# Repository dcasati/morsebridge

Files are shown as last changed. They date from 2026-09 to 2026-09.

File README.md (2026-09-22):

# MorseBridge

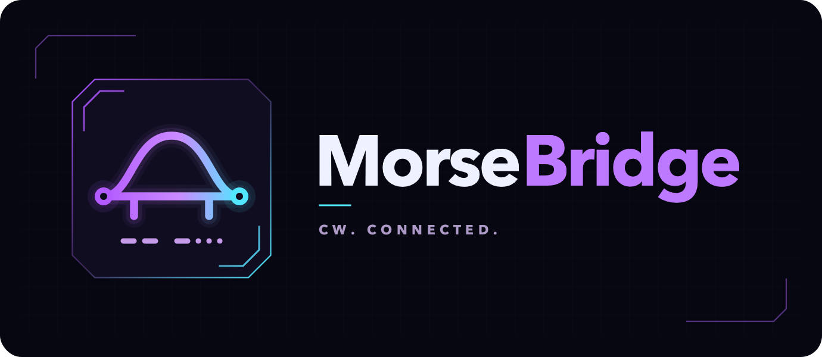
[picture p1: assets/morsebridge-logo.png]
MorseBridge - CW. CONNECTED.


**Use your Morse paddle with your favorite CW app, over USB or Bluetooth.**
MorseBridge is a small adapter built around the **Waveshare ESP32-S3-Zero**.
It turns paddle presses into keyboard input; the app handles Morse timing and
sidetone. No display, menus or standalone computer are needed when using a phone.

<p align="center">
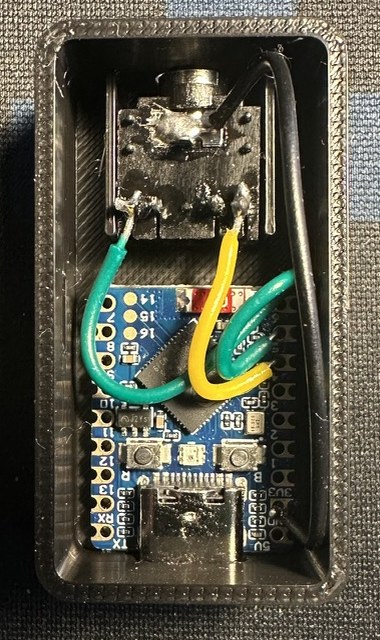
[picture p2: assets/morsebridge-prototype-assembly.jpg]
MorseBridge prototype with the lid removed, showing the jack, wiring and ESP32 board
  
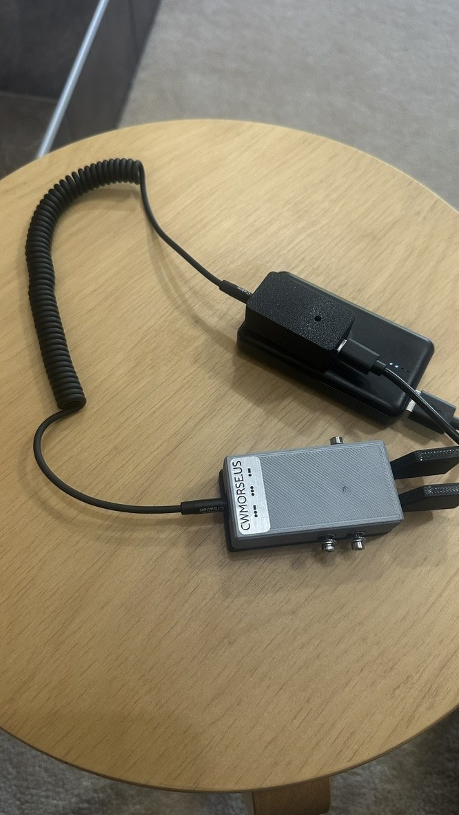
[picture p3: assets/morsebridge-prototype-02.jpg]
Second user-supplied MorseBridge prototype photo
  
</p>

## How it connects

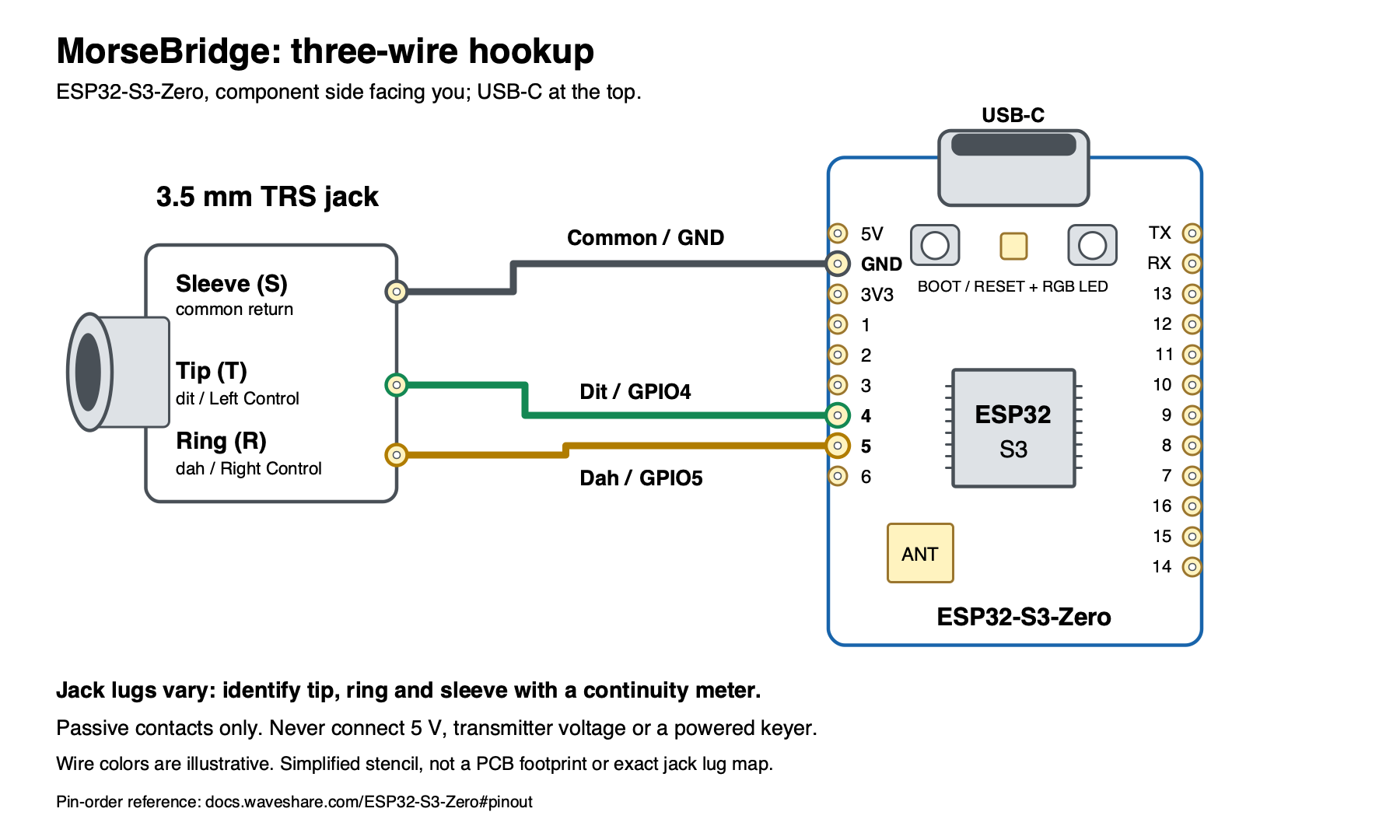
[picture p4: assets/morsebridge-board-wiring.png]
ESP32-S3-Zero component-side wiring: jack tip to GPIO4 for dit, ring to GPIO5 for dah, and sleeve to GND, with USB-C at the top.


**USB-C is at the top; the board's component side faces you.** Jack terminals
are symbolic: identify the actual tip, ring and sleeve lugs with a continuity meter.

**USB takes priority when a host configures it.** With a charger or power bank,
use Bluetooth instead. Only one connection sends paddle input at a time.

## Get started

You need an **ESP32-S3-Zero (4 MB flash / 2 MB PSRAM)**, a passive iambic
paddle, a 3.5 mm TRS jack and a USB-C data cable.

1. **Wire the jack:** tip to **GPIO4** (dit), ring to **GPIO5** (dah), sleeve to
   **GND**. Verify the jack's lug mapping before soldering.
2. **Download the [latest firmware release](https://github.com/dcasati/morsebridge/releases/latest)**
   and follow the [flashing instructions](docs/flashing.md). No compiling required.
3. **Connect:** use a USB-C data cable to your phone/computer, or power from a
   charger/power bank and pair with **MorseBridge** over Bluetooth.
4. **Configure the app:** enable keyboard/paddle input, set **dit = Left Control**
   and **dah = Right Control**, then open its sending screen.
5. **Release both paddles to arm**, then start sending. Repeat after changing
   connections. [Morse-it setup details](docs/guide.md#iphone-and-morse-it).

**Passive contacts only:** never connect transmitter/keying voltage, 5 V or a
powered keyer output to the GPIOs. Straight-key mode is not supported yet.

## Known-working apps

User-confirmed; individual USB/Bluetooth and device/browser combinations are
not yet documented.

- [Morse Code Complete: Learn CW](https://apps.apple.com/ca/app/morse-code-complete-learn-cw/id6759272226)
- [Morse-It](https://apps.apple.com/ca/app/morse-it/id284942940)
- [VBand](https://hamradio.solutions/vband/)

## Status light

| Color | Meaning |
| --- | --- |
| Cyan | USB ready |
| Green | Bluetooth ready |
| Blue | Waiting for a connection |
| Amber | Waiting for readiness, USB resume or paddle release |
| Red | Connection/report error; reset and check [diagnostics](docs/guide.md#diagnostics-and-behavior) |

A Mac/PC data connection selects USB even when you only open a serial monitor.
Use a charger or power bank when you want Bluetooth input on another device.

## Print a case

**45 x 24 x 16 mm enclosure**, with a snap-fit lid and release slots.

Download and print the linked base and lid as a matching pair. The prototype
was printed in **PLA+**; **PETG is also an option**. Check fit and clip strength
before installing the electronics.

[Base STL](enclosure/v6/morsebridge_base_45x24x16_v6.stl) |
[Lid STL](enclosure/v6/morsebridge_lid_45x24x16_v6.stl) |
[Printing and fit notes](enclosure/FIT-CHECK.txt)

## Guides

[Build, flash and BOOT recovery](docs/guide.md#build) |
[Troubleshooting](docs/guide.md#diagnostics-and-behavior) |
[BLE-only rollback](docs/guide.md#ble-only-rollback) |
[Editable wiring diagram](assets/morsebridge-board-wiring.excalidraw)

## License

[MIT](LICENSE). Adapted from [Morse Tutor](https://github.com/dcasati/morse-tutor),
retaining the original **Copyright (c) 2019 Bruce E. Hall** notice.
[Provenance details](docs/guide.md#provenance-and-license).

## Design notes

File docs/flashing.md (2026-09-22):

# Flash a firmware release

For the **Waveshare ESP32-S3-Zero with 4 MB flash and 2 MB PSRAM** only.
This is not firmware for the original ESP32-WROOM, a XIAO board, or the
ESP32-S3-Zero-N8R8.

## 1. Download

From the [latest release](https://github.com/dcasati/morsebridge/releases/latest),
download the firmware ZIP and `SHA256SUMS.txt`. Use the firmware ZIP, **not**
GitHub's automatically generated "Source code" archives.

Verify the ZIP before extracting it. On macOS:

```sh
shasum -a 256 -c SHA256SUMS.txt
```

On Linux, use `sha256sum -c SHA256SUMS.txt`. On Windows, use
`Get-FileHash .\morsebridge-v0.1.0-esp32s3-zero.zip -Algorithm SHA256` in
PowerShell and compare the result with `SHA256SUMS.txt`.

Extract the ZIP. It contains:

| File | Flash address |
| --- | --- |
| `bootloader.bin` | `0x0` |
| `partitions.bin` | `0x8000` |
| `boot_app0.bin` | `0xe000` |
| `firmware.bin` | `0x10000` |

`FLASHING.md`, `build-details.json`, `LICENSE` and a separate `SHA256SUMS.txt`
for the extracted files are included. **Do not flash `firmware.bin` at `0x0`.**

## 2. Install the flashing tool

Install Python 3 if needed, then create a virtual environment.

macOS / Linux:

```sh
python3 -m venv .venv
source .venv/bin/activate
```

Windows PowerShell:

```powershell
py -m venv .venv
.\.venv\Scripts\Activate.ps1
```

In the activated environment:

```sh
python -m pip install esptool==5.2.0
```

Arduino IDE and the ESP32 board package are not needed for this method.

## 3. Enter download mode and flash

Use a **USB data cable** and close serial monitors. Hold **BOOT**, tap and
release **RESET**, then release BOOT. Alternatively, hold BOOT while plugging
the board into USB.

Find the board's serial port: typically `/dev/cu.usbmodem...` on macOS,
`/dev/ttyACM0` on Linux, or `COM3` on Windows. The name can change in BOOT mode.
Unplug/replug to distinguish it from other serial devices.

In a terminal with the virtual environment active, change into the extracted
firmware folder. Replace `PORT` below with the board's actual port, then run
this command as **one line**:

```sh
python -m esptool --chip esp32s3 --port PORT --baud 115200 write-flash 0x0 bootloader.bin 0x8000 partitions.bin 0xe000 boot_app0.bin 0x10000 firmware.bin
```

Wait for verification to finish, then tap **RESET** if the board remains in
download mode.

This command writes four separate regions; it does **not** run `erase-flash`
or overwrite the NVS region at `0x9000`-`0xdfff`. Existing MorseBridge Bluetooth
bonds are preserved when updating from its current partition layout. Back up
any important data before replacing unrelated firmware; its partition layout
may differ. No merged whole-flash image is included.

## 4. Start using MorseBridge

Release both paddles after connection. **Cyan** means USB ready; **green**
means Bluetooth ready. Configure the app for **dit = Left Control** and
**dah = Right Control**.

A Mac/PC USB data connection selects wired input. To use Bluetooth with your
phone, power the board from a charger or power bank instead.

For troubleshooting, source builds or BLE-only rollback, see the
[setup and firmware guide](https://github.com/dcasati/morsebridge/blob/main/docs/guide.md).

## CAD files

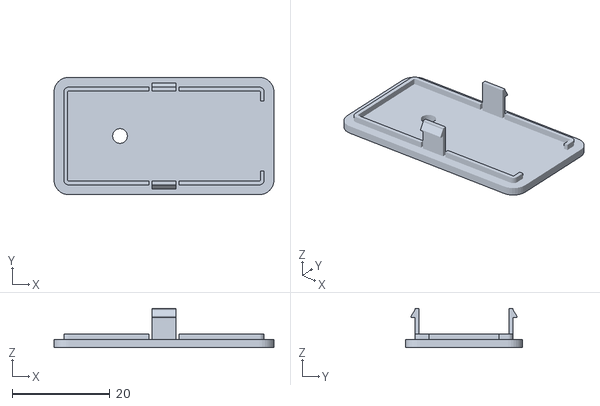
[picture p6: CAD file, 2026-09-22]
enclosure/v6/morsebridge_lid_45x24x16_v6.stl
45.0 x 24.0 x 8.00

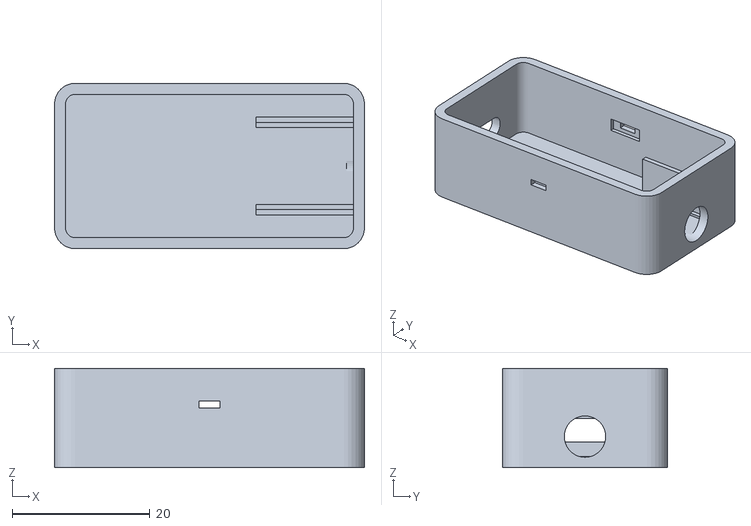
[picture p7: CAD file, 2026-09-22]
enclosure/v6/morsebridge_base_45x24x16_v6.stl
45.0 x 24.0 x 14.4

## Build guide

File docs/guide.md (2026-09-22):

# MorseBridge setup and firmware reference

[Back to the overview](../README.md)

Detailed instructions for building, configuring and troubleshooting MorseBridge.
Run all shell commands from the **repository root**, not from `docs/`.

- [Hardware and wiring](#hardware-and-wiring)
- [Build](#build)
- [Upload and BOOT recovery](#upload-and-boot-recovery)
- [BLE-only rollback](#ble-only-rollback)
- [iPhone and Morse-it](#iphone-and-morse-it)
- [Diagnostics and behavior](#diagnostics-and-behavior)
- [Enclosure prototype](#enclosure-prototype)

## Validation record

The previous BLE-only build
(`c055d0d`) was flashed and used successfully with paddles in Morse-it.
The dual-transport build passes host tests and the pinned ESP32-S3 build.
Firmware `70bdd09` was flashed on the S3 on 2026-09-22 without erasing NVS.
macOS recognizes **MorseBridge as a USB HID keyboard** with diagnostic CDC.
Live diagnostics show USB configured, awake and armed, a queued neutral report,
and the existing bonded BLE connection retained with BLE paddle reports disabled.
Application compatibility is [user-confirmed in the overview](../README.md#known-working-apps). Exact transport/platform
combinations and physical handoffs remain to be recorded; enumeration alone
does not establish application compatibility.

## Hardware and wiring

Target: [Waveshare ESP32-S3-Zero](https://www.waveshare.com/wiki/ESP32-S3-Zero),
ESP32-S3FH4R2, **4 MB flash, 2 MB QSPI PSRAM**, native USB-C.

| Passive 3.5 mm TRS jack | Board connection | Function |
| --- | --- | --- |
| Tip | GPIO4 | Dit / Left Control |
| Ring | GPIO5 | Dah / Right Control |
| Sleeve | GND | Common return |

Both contacts are configured as `INPUT_PULLUP`: a contact is pressed when it
closes to GND. Verify the actual paddle plug and jack lug mapping with a
continuity meter before connecting; some paddles reverse tip/ring. Swap those
two leads if needed. The numbers above are **GPIO numbers**, not physical pin
positions.

GPIO4 and GPIO5 are exposed, non-strapping pins, separate from native USB
GPIO19/20, flash/PSRAM and the onboard GPIO21 WS2812. Leave GPIO19/20 alone.
For noisy or longer wiring, optional external **10 kOhm pullups from each input
to 3.3 V** can supplement the internal pullups. Keep wiring short.
**Never connect 5 V, transmitter/keying voltage, or a powered keyer output to
these GPIOs.** This input is for isolated passive contacts only, not a
transmitter keying interface.

Power the board through USB-C from a computer, USB supply or power bank. Boot
does not wait for Serial or a USB host. Some power banks shut off with a
low-current load; use an always-on/low-current mode or an appropriate supply.
No battery measurement or charging circuit is implemented. The HID battery
service reports a fixed 100% for this USB-powered device.

## Build

For a prebuilt binary, use the [latest firmware release](https://github.com/dcasati/morsebridge/releases/latest)
and [release flashing instructions](flashing.md). The steps below are for
building from source.

Use **Arduino ESP32 core 3.3.8**, which includes the BLE library. Do not install
a third-party `ESP32 BLE Keyboard` or `NimBLE-Arduino` library for this sketch.
The build script checks the installed core version and does not install or
upgrade dependencies automatically.

```sh
arduino-cli core update-index \
  --additional-urls https://espressif.github.io/arduino-esp32/package_esp32_index.json
arduino-cli core install esp32:esp32@3.3.8 \
  --additional-urls https://espressif.github.io/arduino-esp32/package_esp32_index.json
bash scripts/test.sh
bash scripts/build.sh
```

The host tests require a C++17 compiler (`c++`, or set `CXX`). Set `ARDUINO_CLI`
if the CLI is not on PATH. Standard `ARDUINO_DIRECTORIES_DATA` and
`ARDUINO_DIRECTORIES_USER` environment variables can isolate the Arduino
installation from other projects.

Exact tested FQBN (also used by `scripts/build.sh`):

```sh
FQBN='esp32:esp32:esp32s3:USBMode=default,CDCOnBoot=default,MSCOnBoot=default,DFUOnBoot=default,UploadMode=default,CPUFreq=240,FlashMode=qio,FlashSize=4M,PartitionScheme=huge_app,PSRAM=enabled,DebugLevel=none,EraseFlash=none'
arduino-cli compile --fqbn "$FQBN" --warnings all \
  --build-path "$PWD/build/esp32s3" MorseBridge
```

Equivalent Arduino IDE selections:

| Setting | Value |
| --- | --- |
| Board | ESP32S3 Dev Module |
| ESP32 package version | 3.3.8 |
| USB Mode | USB-OTG (TinyUSB) |
| USB CDC On Boot | Disabled (firmware starts diagnostic CDC manually) |
| USB Firmware MSC / DFU On Boot | Disabled |
| Upload Mode | UART0 / Hardware CDC |
| CPU Frequency | 240 MHz |
| Flash Mode / Size | QIO 80 MHz / 4 MB |
| Partition Scheme | Huge APP (3 MB No OTA / 1 MB SPIFFS) |
| PSRAM | QSPI PSRAM |
| Core Debug Level | None |
| Erase All Flash Before Sketch Upload | Disabled (normally) |

The large app partition leaves ample room; the filesystem partition is unused
and no OTA updater is implemented. Build output is ignored by Git under
`build/esp32s3/`, including `MorseBridge.ino.bin`, its ELF, bootloader, partition
table and merged image. Use the CLI upload command below so all images go to
their correct offsets, rather than flashing the app binary at address zero.
HID and diagnostic CDC are registered before `USB.begin()`: do not enable CDC
on boot or change to Hardware CDC/JTAG. The sketch rejects those settings.
The prototype retains Arduino's default Espressif USB VID/PID; these are not a
commercial VID/PID assignment for MorseBridge.

**S3 backend note:** core 3.3.8 builds ESP32-S3 with **NimBLE**, whereas the
original ESP32 transport used Bluedroid. This project uses the core's unified
`BLE*` APIs with native NimBLE connection/security/subscription callbacks,
synchronous advertising-start results and automatically managed CCCDs. It
does not fake a Bluedroid compile flag or use a manually added `BLE2902`.
The version is pinned because BLE APIs and backend defaults differ across
core versions.

## Upload and BOOT recovery

Use a known **USB data cable**. Once the board is visible, find its actual port:

```sh
arduino-cli board list
```

With `FQBN` set exactly as above, replace the example port with the detected one:

```sh
PORT='/dev/cu.usbmodem...'
arduino-cli upload --fqbn "$FQBN" --port "$PORT" \
  --input-dir "$PWD/build/esp32s3" MorseBridge
```

If the board is not detected or the previous sketch prevents USB enumeration,
hold **BOOT**, tap and release **RESET**, then release BOOT. Alternatively hold
BOOT while plugging in USB-C. Select the newly enumerated port and upload.
After upload, tap RESET if it remains in the ROM download loader. The serial
port name can change between ROM download mode and the running firmware.
If no USB device appears even in BOOT mode, check the cable, port and board
power first; software cannot flash a device that the host does not enumerate.

Normal uploads preserve Bluetooth bonds in NVS. For persistent stale-bond
problems, **forget the device on the iPhone and deliberately erase board flash
before reuploading**: in Arduino IDE enable *Erase All Flash Before Sketch
Upload* for one upload, then restore Disabled. This removes **all** board data,
including bonds, not just the application. No erase is performed by the build
script, and there is no bond-reset button gesture or serial command.

### BLE-only rollback

The known BLE-only version is commit `c055d0d675da2caa005ef69cd9abcd4ecbf71870`.
Build it separately without switching branches or disturbing current edits:

```sh
mkdir -p build/ble-rollback
git archive c055d0d675da2caa005ef69cd9abcd4ecbf71870 MorseBridge scripts/build.sh \
  | tar -x -C build/ble-rollback
(cd build/ble-rollback && bash scripts/build.sh)
```

Enter BOOT mode as described above, select its port and upload the rollback
images using the **old** USB configuration:

```sh
BLE_FQBN='esp32:esp32:esp32s3:USBMode=hwcdc,CDCOnBoot=cdc,MSCOnBoot=default,DFUOnBoot=default,UploadMode=default,CPUFreq=240,FlashMode=qio,FlashSize=4M,PartitionScheme=huge_app,PSRAM=enabled,DebugLevel=none,EraseFlash=none'
arduino-cli upload --fqbn "$BLE_FQBN" --port "$PORT" \
  --input-dir "$PWD/build/ble-rollback/build/esp32s3" build/ble-rollback/MorseBridge
```

## iPhone and Morse-it

1. **Wired:** connect the board directly to the unlocked iPhone 15 Pro Max with
   a USB-C **data** cable; Bluetooth pairing is not required. Expect cyan after
   releasing the paddles. Follow any iOS accessory-unlock prompt.
   **Wireless:** power from a charger/power bank, then pair with **MorseBridge**
   in iPhone **Settings > Bluetooth**. Expect green after release. Pairing uses
   bonded, encrypted JustWorks without MITM protection; pair in a trusted place.
2. In Morse-it, open **Settings > Hardware Interface > Iambic/Memory** and enable
   **Keyboard Enabled**. Set **Dot = Left Control**, **Dash = Right Control**.
3. Set **Key Type = Iambic A** or **Iambic B** to match your preference, and choose
   speed/sidetone settings in Morse-it.
4. Open **Tap** or **Start Sending Trainer**. In a keyboard event viewer, tap
   its text area to give it focus before trying the paddles.
5. Release **both** paddles after connection, route changes, resume or
   subscription changes to arm, then send normally.

### Automatic transport selection

USB is selected only when its host configures the device, not from cable power,
CDC DTR or an open serial monitor. Both transports may remain connected, but
paddle presses go to only one. During a BLE-to-USB handoff, BLE gets a neutral
report first; if it cannot accept the release, the firmware requests a BLE
disconnect and waits for that callback before enabling USB reports. Each newly
selected route sends neutral and waits for both contacts to be released.

**A Mac/PC data connection selects USB too**, even if you only wanted a serial
monitor. To use BLE with the iPhone, power the board from a charger/power bank
instead. A suspended USB host retains priority (amber) until resume or USB
unmount; the firmware does not send duplicate keys through BLE during sleep.
If the board loses power when unplugged, it restarts when powered again.
With independent power, USB unmount permits BLE fallback; without VBUS sensing,
loss of data wires alone may look like host suspension rather than unmount.

Left Control is modifier `0x01`, Right Control is `0x10`, and a squeeze is
`0x11`. Each report has exactly eight bytes: modifier, zero reserved byte, six
zero key usages. Releases send modifier `0x00`; holds remain held without
artificial repeats or tap conversion. These are modifier events, **not
printable text**, so an ordinary text field may show nothing.

If Bluetooth says connected but Morse-it does nothing, check keyboard mapping,
the active sending screen/focus, and that both paddles were released. Disconnect
other hosts that may reconnect to the board. If iOS has cached an earlier
keyboard profile, forget the old device and pair again. The distinct name
avoids confusing it with *Morse Tutor*, but changing the name alone does not
clear a cached identity/bond on the same physical board.

**Name migration:** iOS may keep displaying the former name, *Morse Paddle*,
for an existing bond after the firmware rename. Reconnect first; if the label
stays cached, forget that device on the iPhone and pair with **MorseBridge**.
The rename does not erase bonds or change the HID report format or GPIO mapping.

## Diagnostics and behavior

USB diagnostic CDC is 115200 baud, with **no boot wait or host-delivery wait**.
Opening a serial monitor can reset some boards/USB configurations and interrupt
BLE; reconnect and release both paddles afterward. Logging is best effort:
without a reading host, messages may be dropped rather than delay keying.
All firmware output uses one non-waiting writer guard and reserves a complete
line in a fixed 192-byte buffer, draining it in FIFO-sized chunks without
interleaving other lines. The pinned core's CDC TX FIFO is only 64 bytes.
Queuing directly to TinyUSB avoids both the old
HWCDC full-buffer stall and core 3.3.8's `USBCDC::write` behavior that drops all
writes with a zero timeout. No code waits for the host to consume diagnostics.
BLE callbacks never wait for another log writer. Dropped lifecycle/error
messages are counted and reported as `LOG: dropped ...` once space returns;
current GPIO/USB/BLE snapshots resume automatically.
There are boot messages, USB/BLE error messages and status transitions.
Paddle diagnostics are currently enabled (`MORSEBRIDGE_DEBUG=1` in
`MorseBridge/PaddleDebug.h`). Set that default to `0`, or compile with
`-DMORSEBRIDGE_DEBUG=0`, to disable the additional snapshots.
The former `MORSE_PADDLE_DEBUG` compile flag remains a compatibility alias.

### Checking the jack and paddle over USB

Open the board's serial port at **115200 baud**. No iPhone connection is needed
to see the input levels, even if BLE startup fails. Press/release each paddle,
then squeeze both. Expect:

| Contact state | GPIO4 | GPIO5 |
| --- | --- | --- |
| Both released | HIGH | HIGH |
| Dit held | LOW | HIGH |
| Dah held | HIGH | LOW |
| Both held | LOW | LOW |

Example snapshot:

```text
DBG GPIO4=LOW GPIO5=HIGH edges=1/0 C=1 A=1 S=1 U=0 R=0 Q=1 M=00 T=USB UC=1 US=0 UR=1 UQ=2 UM=01
```

`edges` counts **raw transitions** on GPIO4/GPIO5 since boot, including contact
bounce; a short tap can increase the counters even if the sampled display has
already returned to HIGH. Changes are summarized at most ten times per second,
with a heartbeat every two seconds. The logger never waits for USB buffer
space, and retains transition totals while there is no reading host.

The BLE flags are `C` connected, `A` encrypted and bonded, `S` HID notifications
subscribed, `U` host suspended, and `R` ready/armed. `Q` counts reports accepted
by the local BLE stack since boot, **not confirmed delivery to Morse-it**.
`M` is the last accepted report's modifier byte: `01` dit, `10` dah, `11` both,
`00` released. It is historical, so check the connection flags alongside it.
`T` is the selected route (`USB`, `BLE`, `NONE`); `UC` is USB configured,
`US` is USB suspended, `UR` is USB armed, `UQ` counts locally queued USB reports,
and `UM` is their last modifier byte. USB counters also do **not** confirm
delivery to Morse-it. On a working USB route, BLE `R=0` is expected even when
Bluetooth is still connected.

If neither input changes, check the **sleeve/common wire to GND**, the jack's
tip/ring lugs (not its switched lugs), and plug continuity with power unplugged.
If an input stays LOW with the paddle released, check for a short or incorrect
jack lug; the firmware cannot arm until both inputs are HIGH. If the input
levels change, check the selected route: USB needs `UC=1 US=0 UR=1`; BLE needs
`C/A/S/R=1 U=0`. If its report counters/modifiers change correctly, check the
host receiving those reports, Morse-it's keyboard mapping and event-viewer focus.

| Serial status | Meaning |
| --- | --- |
| Waiting | Waiting for USB configuration or BLE connection |
| Waiting for HID subscription, route release, or USB resume | Link exists but reports are not ready |
| Release BOTH paddles | Initial neutral report/released contacts required |
| BLE ready | Encrypted, bonded, subscribed and armed |
| USB ready | Configured, awake and armed; BLE paddle reports suppressed |
| ERROR | Read the preceding USB/BLE error, then reset/power-cycle |

### Status light

The onboard **GPIO21 RGB LED** lights at low brightness as soon as firmware starts:

| Color | Meaning |
| --- | --- |
| Blue | Powered, waiting for a USB host or BLE connection |
| Amber | Waiting for HID readiness, old-route release, USB resume or paddle release |
| Green | BLE ready and paddles armed |
| Cyan | USB ready and paddles armed |
| Red | Selected/available route initialization, pairing, advertising or report error |

The onboard LED uses **RGB byte order, not GRB**, as documented in the
[Waveshare FAQ](https://docs.waveshare.com/ESP32-S3-Zero/FAQ).
Using GRB swaps ready/green and error/red.

The color changes only with status, never on each paddle press. A persistent
WS2812 frame is sent using asynchronous RMT, so the paddle loop does not wait
for LED transmission. A transmit failure or 20 ms completion timeout logs an
error and disables further LED updates without stopping HID. The last color
can remain latched after such a failure; check Serial if its meaning is unclear.
The LED is a firmware indicator, not an independent power-good indicator: it
may remain off in the ROM bootloader or if startup/LED hardware fails.

The advertising watchdog reports an error only after advertising has been
continuously absent for two seconds without a connection. Normal advertising
shutdown just before a connection callback is not itself an error.

Contacts debounce independently for 5 ms on each edge. The loop yields for
1 ms; BLE/USB scheduling adds latency, so this is not a hard real-time keyer.
A new connection, selected route, resubscription or resume sends neutral before arming and
requires both contacts released. Security and subscription callbacks received
before the connection callback are retained; disconnect clears them for the
next session. Failed notifications retry at 10 ms intervals,
with three consecutive failures causing an explicit error and disconnect to
release keys. Normal disconnects restart advertising automatically. Initialization
and services are retained instead of allocating new services on reconnect.
Pairing failures and advertising failures latch an error rather than silently
pretending to be ready or repeatedly restarting.
USB uses the same eight-byte report and ID 1 (ID 0 in boot protocol).
USB reports queue without waiting for host completion. Busy endpoints retry
without resetting debounce; a pending report blocked for 250 ms, or three
consecutive queue failures at 10 ms intervals, latches an error and detaches
USB to release the host's keyboard state. Reset is required to restore a
faulted transport. A failure on an unused transport does not stop a healthy
selected one; consult diagnostic error messages.

The host tests cover debounce/bounce, rollover, hold/release/squeeze report bytes,
bond/encryption/subscription gating, reconnection, suspend/resume, neutral-send
failure, service reuse, bounded notification failures, advertising failures and
the actual sketch's host-independent startup/GPIO mapping/status logging.
Dual-route cases cover USB-only, BLE-only/power-only, both hosts, held-paddle
handoffs, delayed BLE disconnects, failed releases, USB busy/failure/boot
protocol, unplug/replug, suspend/resume, and missing/full diagnostic CDC.
They simulate both APIs; they do not prove USB enumeration, iOS recognition,
over-the-air pairing or latency.

Before relying on this build, verify on the actual S3 board: first pairing,
individual holds/releases and squeeze in Morse-it, reconnect/power-cycle with
both paddles held, resume, and operation on USB power without a computer.
For the experimental wired mode, verify USB HID + CDC enumeration on a computer
without opening a monitor; direct USB-C/iPhone Morse-it input with Bluetooth
off; both transports connected with no double-keying; cyan versus green route
indication; handoffs while held; and recovery through BOOT mode. Do not interpret
successful USB enumeration alone as successful Morse-it input.

## Enclosure prototype

Download the **V6 fit-check prototype** without running the generator:
[base STL](../enclosure/v6/morsebridge_base_45x24x16_v6.stl) |
[lid STL](../enclosure/v6/morsebridge_lid_45x24x16_v6.stl) |
[mesh-check report](../enclosure/v6/mesh-checks.json).
On each STL's GitHub page, use **Download raw file** to save it for your slicer.
Print both V6 parts together and read the [fit notes](../enclosure/FIT-CHECK.txt)
first. These are nominal geometry checks, not a guarantee of physical fit.

The editable **MorseBridge** enclosure generator and fitting notes are in
[`enclosure/`](../enclosure/). Generate the current V6 pair with:

```sh
python3 -m venv .venv-enclosure
.venv-enclosure/bin/pip install -r enclosure/requirements.txt
.venv-enclosure/bin/python enclosure/prototype.py --output build/enclosure
```

Outputs are `morsebridge_base_45x24x16_v6.stl` and
`morsebridge_lid_45x24x16_v6.stl`: **45 x 24 x 16 mm assembled outside**,
41.8 mm internal length and 12.8 mm floor-to-lid clearance.
The USB-C opening is rounded 9.5 x 3.4 mm,
the jack opening is 6 mm diameter, and the LED opening is 3 mm diameter.
V6 keeps the four PCB pads and USB-end guides removed, retaining the jack cradle.
The lid uses two flexible snap clips with catches and side release slots, plus
a shorter locating lip with 0.4 mm clearance per side. Print both V6 parts;
earlier lids are not compatible. The prototype was printed in PLA+; PETG is
also an option. Dry-fit the empty case before installing electronics.
The LED hole centre is moved 1 mm toward USB-C, to 13.5 mm from that end.
USB opening height is unchanged; the PCB needs separate insulated retention.
Read `enclosure/FIT-CHECK.txt` before printing: physical fit, LED alignment,
and final mechanical retention are not qualified.

## Provenance and license

`BlePaddleKeyboard.{h,cpp}`, `PaddleInput.h`, and their original host tests/fakes
were adapted from
[`dcasati/morse-tutor` at `01b5c93f9198a7b5ae5febc1caab8cd6b04c2255`](https://github.com/dcasati/morse-tutor/commit/01b5c93f9198a7b5ae5febc1caab8cd6b04c2255).
This separate project adds the S3/headless entry point, core NimBLE adaptation,
stricter neutral/subscription/resume handling, additional tests and board-specific
instructions. It does not modify the original tutor.

Distributed under the [MIT license](../LICENSE), retaining the upstream
**Copyright (c) 2019 Bruce E. Hall** notice; the original tutor is not represented
as newly authored here. Arduino-ESP32 and its bundled BLE/ESP-IDF components
retain their own licenses and are installed separately, not vendored.

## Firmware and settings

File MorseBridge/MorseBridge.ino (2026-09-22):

#include <Arduino.h>
#include "BlePaddleKeyboard.h"
#include "PaddleDebug.h"
#include "StatusLed.h"
#include "PaddleRouter.h"

#if ARDUINO_USB_CDC_ON_BOOT || ARDUINO_USB_MODE != 0
#error "Select USB-OTG (TinyUSB), USB CDC On Boot Disabled"
#endif

namespace {
constexpr uint8_t ditPin = 4;
constexpr uint8_t dahPin = 5;
bool statusLogged = false;
MorseBle::Status lastStatus = MorseBle::Status::Waiting;
StatusLed statusLed;
MorseBridge::PaddleRouter router;
#if MORSEBRIDGE_DEBUG
PaddleDebug paddleDebug;
#endif

void logStatus() {
  const auto status = router.status();
  statusLed.update(status, millis());
  if (statusLogged && status == lastStatus) return;
  statusLogged = true;
  lastStatus = status;
  switch (status) {
    case MorseBle::Status::Waiting:
      PaddleLog::println("Status: waiting; connect USB data cable or pair with MorseBridge");
      break;
    case MorseBle::Status::Connecting:
      PaddleLog::println("Status: waiting for HID subscription, route release, or USB resume");
      break;
    case MorseBle::Status::ReleasePaddles:
      PaddleLog::println("Status: release BOTH paddles to arm");
      break;
    case MorseBle::Status::Ready:
      PaddleLog::println("Status: BLE ready; timing and sidetone are generated by Morse-it");
      break;
    case MorseBle::Status::UsbReady:
      PaddleLog::println("Status: USB ready; Bluetooth paddle reports suppressed");
      break;
    case MorseBle::Status::Error:
      PaddleLog::println("Status: ERROR; inspect USB/BLE messages, then reset/power-cycle");
      break;
  }
}
}

void setup() {
  pinMode(ditPin, INPUT_PULLUP);
  pinMode(dahPin, INPUT_PULLUP);
  DebugSerial.begin(115200);
  MorseUsb::begin();
  statusLed.begin();
  statusLed.update(MorseBle::Status::Waiting, millis());
  PaddleLog::println("MorseBridge: Waveshare ESP32-S3-Zero; USB + BLE HID, USB priority");
  PaddleLog::println("Inputs: dit GPIO4, dah GPIO5, active LOW; debounce 5 ms");
  MorseBle::begin();
  router.update(false, false);
  logStatus();
}

void loop() {
  const bool ditDown = digitalRead(ditPin) == LOW;
  const bool dahDown = digitalRead(dahPin) == LOW;
  router.update(ditDown, dahDown);
  logStatus();
  PaddleLog::poll();
#if MORSEBRIDGE_DEBUG
  paddleDebug.sample(ditDown, dahDown, millis(), MorseBle::diagnostics(),
                     MorseUsb::diagnostics(), router.route());
#endif
  delay(1);
}

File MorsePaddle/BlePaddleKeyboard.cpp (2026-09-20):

#include "BlePaddleKeyboard.h"
#include "PaddleInput.h"

#include <Arduino.h>
#include <BLEDevice.h>
#include <BLEHIDDevice.h>
#include <BLESecurity.h>
#include <atomic>

#if !defined(CONFIG_IDF_TARGET_ESP32S3) || !defined(CONFIG_NIMBLE_ENABLED)
#error "Morse Paddle requires ESP32-S3 with the Arduino 3.3.8 NimBLE stack"
#endif

namespace MorseBle {
namespace {

// Standard keyboard report: modifiers, reserved byte, six key usages.
uint8_t reportMap[] = {
  0x05, 0x01, 0x09, 0x06, 0xA1, 0x01, 0x85, 0x01,
  0x05, 0x07, 0x19, 0xE0, 0x29, 0xE7, 0x15, 0x00,
  0x25, 0x01, 0x75, 0x01, 0x95, 0x08, 0x81, 0x02,
  0x95, 0x01, 0x75, 0x08, 0x81, 0x01,
  0x95, 0x05, 0x75, 0x01, 0x05, 0x08, 0x19, 0x01,
  0x29, 0x05, 0x91, 0x02, 0x95, 0x01, 0x75, 0x03, 0x91, 0x01,
  0x95, 0x06, 0x75, 0x08, 0x15, 0x00, 0x25, 0x65,
  0x05, 0x07, 0x19, 0x00, 0x29, 0x65, 0x81, 0x00, 0xC0
};

BLEServer *server = nullptr;
BLECharacteristic *input = nullptr;
std::atomic<bool> subscribed{false};
std::atomic<bool> active{false};
std::atomic<bool> connected{false};
std::atomic<bool> authenticated{false};
std::atomic<bool> suspended{false};
std::atomic<bool> restartAdvertising{false};
std::atomic<bool> failed{false};
std::atomic<bool> reportAccepted{false};
std::atomic<uint32_t> connectionEpoch{0};
PaddleInput paddles;
bool initialized = false;
bool wasReady = false;
uint8_t lastModifiers = 0xFF;
uint32_t lastAttempt = 0;
uint32_t observedEpoch = 0;
uint8_t reportFailures = 0;
uint32_t advertisingStartedAt = 0;

bool ready() {
  return active && connected && authenticated && !suspended && !failed
      && subscribed;
}

void clearReport() {
  const KeyboardReport neutral;
  input->setValue(reinterpret_cast<const uint8_t *>(&neutral), sizeof(neutral));
}

void advertisingComplete(BLEAdvertising *) {
  if (active && !connected) {
    failed = true;
    Serial.println("BLE: advertising stopped unexpectedly; restart the ESP32");
  }
}

bool startAdvertising() {
  advertisingStartedAt = millis();
  // NimBLE returns the start result synchronously, unlike Bluedroid GAP events.
  if (BLEDevice::getAdvertising()->start(0, advertisingComplete)) return true;
  failed = true;
  Serial.println("BLE: advertising request failed");
  return false;
}

class ServerCallbacks : public BLEServerCallbacks {
  void onConnect(BLEServer *device, ble_gap_conn_desc *desc) override {
    authenticated = false;
    subscribed = false;
    suspended = false;
    clearReport();
    connected = true;
    ++connectionEpoch;
    if (!active) {
      device->disconnect(desc->conn_handle);
      return;
    }
    Serial.println("BLE: connected; waiting for encrypted HID subscription");
    if (!device->requestConnParams(desc->conn_handle, 12, 24, 0, 400)) {
      Serial.println("BLE: connection interval request failed; using host interval");
    }
  }

  void onDisconnect(BLEServer *) override {
    authenticated = false;
    subscribed = false;
    connected = false;
    ++connectionEpoch;
    restartAdvertising = active.load();
    Serial.println("BLE: disconnected");
  }
};

class SecurityCallbacks : public BLESecurityCallbacks {
  bool onSecurityRequest() override { return active.load(); }
  uint32_t onPassKeyRequest() override { return 0; }
  void onPassKeyNotify(uint32_t) override {}
  bool onConfirmPIN(uint32_t) override { return false; }

  void onAuthenticationComplete(ble_gap_conn_desc *desc) override {
    authenticated = desc->sec_state.encrypted && desc->sec_state.bonded;
    if (!authenticated) {
      failed = true;
      Serial.printf("BLE: pairing failed (encrypted=%u, bonded=%u); forget device and restart\n",
                    unsigned(desc->sec_state.encrypted), unsigned(desc->sec_state.bonded));
      server->disconnect(desc->conn_handle);
    } else {
      Serial.println("BLE: encrypted and bonded");
    }
  }
};

class ReportCallbacks : public BLECharacteristicCallbacks {
  void onSubscribe(BLECharacteristic *, ble_gap_conn_desc *, uint16_t value) override {
    subscribed = (value & 0x01) != 0;
    // Even an unsubscribe/resubscribe between loop iterations must rearm.
    ++connectionEpoch;
  }

  void onStatus(BLECharacteristic *, Status result, uint32_t code) override {
    reportAccepted = result == SUCCESS_NOTIFY;
    if (result != SUCCESS_NOTIFY) {
      Serial.printf("BLE: HID notification failed (%d, %lu)\n",
                    int(result), static_cast<unsigned long>(code));
    }
  }
};

class ControlCallbacks : public BLECharacteristicCallbacks {
  void onWrite(BLECharacteristic *control) override {
    if (control->getLength() == 1 && control->getData()[0] <= 1) {
      const bool suspend = control->getData()[0] == 0;
      if (suspended.exchange(suspend) != suspend) ++connectionEpoch;
    }
  }
};

ServerCallbacks serverCallbacks;
SecurityCallbacks securityCallbacks;
ReportCallbacks reportCallbacks;
ControlCallbacks controlCallbacks;
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

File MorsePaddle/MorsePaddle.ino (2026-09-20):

#include <Arduino.h>
#include "BlePaddleKeyboard.h"

#if !ARDUINO_USB_CDC_ON_BOOT || ARDUINO_USB_MODE != 1
#error "Enable USB CDC On Boot and select Hardware CDC and JTAG"
#endif

namespace {
constexpr uint8_t ditPin = 4;
constexpr uint8_t dahPin = 5;
bool startupFailed = false;
bool statusLogged = false;
MorseBle::Status lastStatus = MorseBle::Status::Waiting;

void logStatus() {
  const auto status = startupFailed ? MorseBle::Status::Error : MorseBle::status();
  if (statusLogged && status == lastStatus) return;
  statusLogged = true;
  lastStatus = status;
  switch (status) {
    case MorseBle::Status::Waiting:
      Serial.println("Status: waiting for iPhone; pair with Morse Paddle");
      break;
    case MorseBle::Status::Connecting:
      Serial.println("Status: connected, waiting for HID subscription or resume");
      break;
    case MorseBle::Status::ReleasePaddles:
      Serial.println("Status: release BOTH paddles to arm");
      break;
    case MorseBle::Status::Ready:
      Serial.println("Status: ready; timing and sidetone are generated by Morse-it");
      break;
    case MorseBle::Status::Error:
      Serial.println("Status: ERROR; inspect BLE messages, then reset/power-cycle");
      break;
  }
}
}

void setup() {
  pinMode(ditPin, INPUT_PULLUP);
  pinMode(dahPin, INPUT_PULLUP);
  Serial.begin(115200);
  Serial.setTxTimeoutMs(0);  // No USB host is required; never wait for log delivery.
  Serial.println("Morse Paddle: Waveshare ESP32-S3-Zero; BLE HID only");
  Serial.println("Inputs: dit GPIO4, dah GPIO5, active LOW; debounce 5 ms");
  startupFailed = !MorseBle::begin();
  logStatus();
}

void loop() {
  if (!startupFailed) {
    MorseBle::update(digitalRead(ditPin) == LOW, digitalRead(dahPin) == LOW);
  }
  logStatus();
  delay(1);
}

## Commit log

2026-09-20 Add headless ESP32-S3 BLE Morse paddle firmware
    Adapt the proven paddle report/debounce logic to Arduino 3.3.8's S3 NimBLE backend, with native USB CDC diagnostics, headless startup, lifecycle tests and board setup documentation.
2026-09-21 Rename project to MorseBridge and publish firmware and enclosure updates
    Preserve the current BLE diagnostics, nonblocking logging, status LED, reconnect fixes, and enclosure prototype under the MorseBridge identity.
    [BlePaddleKeyboard.cpp, MorseBridge.ino]
2026-09-22 Add USB HID with exclusive USB-priority BLE fallback
    Share the neutral-first report lifecycle, release the old route before handoff, and add cyan USB-ready status. Use bounded TinyUSB HID/CDC queues, exercise transport and failure scenarios, and document the experimental build and BLE rollback.
    [BlePaddleKeyboard.cpp, MorseBridge.ino]
2026-09-22 Publish V6 enclosure STL pair and fit-check source
    Share the 45 x 24 x 16 mm case, removed PCB supports, snap-fit lid and shifted LED opening. Include reproducible STL exports, mesh checks and printing/fit guidance, with direct README links.
    [morsebridge_base_45x24x16_v6.stl, morsebridge_lid_45x24x16_v6.stl]
2026-09-22 Make README a concise visual introduction to MorseBridge
    Add prototype photos and an editable wiring diagram, remove the brand-assets row, and move detailed setup, firmware, recovery and diagnostic instructions into docs/guide.md. Keep safety, app compatib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
2026-09-22 Simplify enclosure introduction for new readers
2026-09-22 Record PLA+ as the prototype enclosure material
    Keep PETG as an alternative rather than a requirement and align the README, guide and fit notes.
2026-09-22 Show board-level ESP32-S3-Zero wiring in the README
    Include PNG, SVG and editable Excalidraw versions, with explicit orientation and jack-lug identification guidance.
2026-09-22 Document prebuilt firmware releases and safe flashing
    Add ESP32-S3-Zero release installation instructions with separate image offsets, checksum verification, BOOT recovery and preservation of existing MorseBridge NVS bonds.
